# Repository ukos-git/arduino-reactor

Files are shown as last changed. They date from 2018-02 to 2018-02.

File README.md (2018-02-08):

# arduino-reactor
This Arduino program controls various parameters during the production of Single Walled Carbon Nanotubes (SWNT). It has a simplification for the Modbus Protocol for a EUROTHERM 2416 PID controller. The readout of pressure and flowmeters is done with analog input values.
The output and input of the arduino is simple ASCII plain text at the USB port.

Readout can be directed to a python based visual terminal manged by [python-swnt-reactor](https://github.com/ukos-git/python-swnt-reactor)

# setup
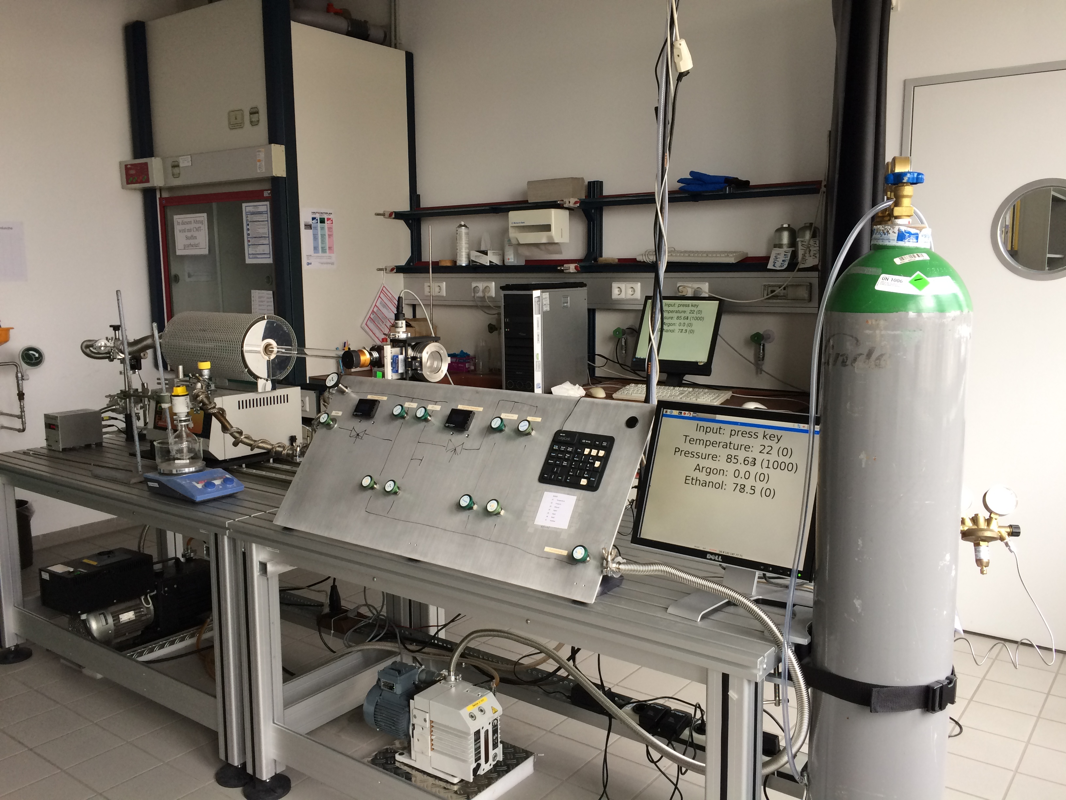
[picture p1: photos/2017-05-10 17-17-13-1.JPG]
photos/2017-05-10 17-17-13-1.JPG

The setup consists of an oven with a centered quarz tube. Inside the quarz pipe the sample is placed. The oven can be moved so that the sample is in the center of the oven during reaction. Reaction (carbon nanotube formation) takes place at 725-900°C with a pressure of around 15mbar.

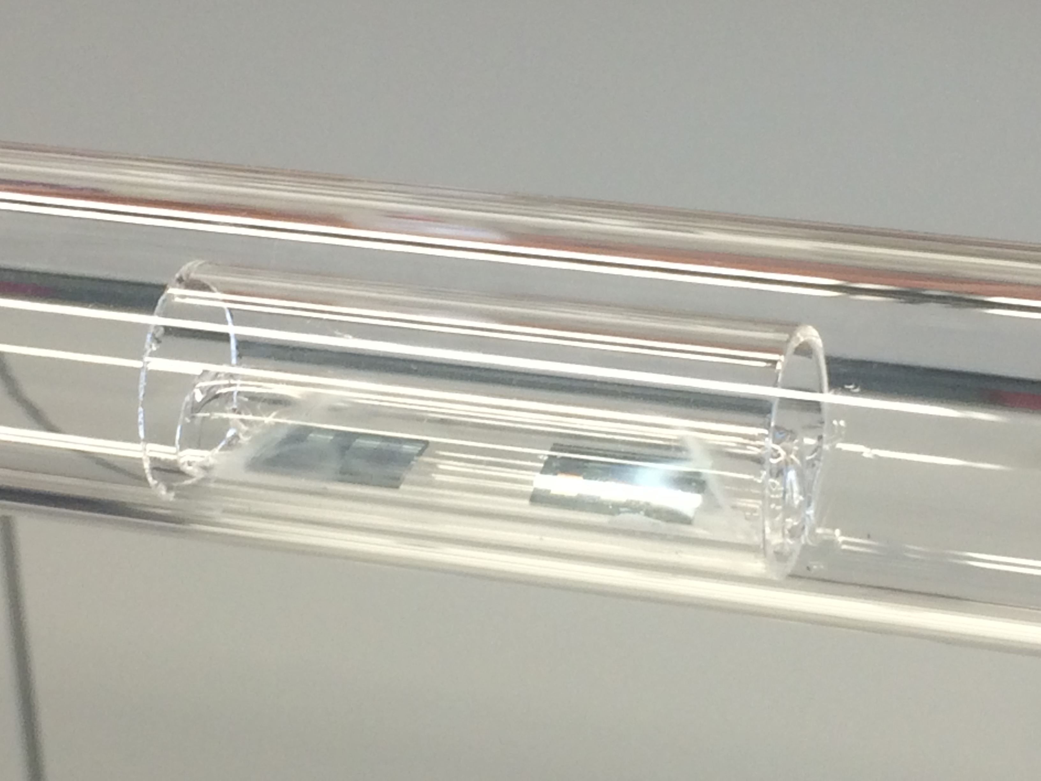
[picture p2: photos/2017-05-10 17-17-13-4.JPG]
sample in quartz tube


The process gas for the Carbon Source is Ethanol, supplied in liquid form and evaporated at 15mbar. Flow is controlled by a Bronkhorst EL-Flow FlowMeter. Digital control of the flowmeter is done in [another project](https://github.com/ukos-git/python-flowmeter).

Reduction of the Catalyst is done via Ar/H<sub>2</sub> gas flow during heat-up.

The Setup can be evacuated to <1mbar and flooded with Argon after reaction.

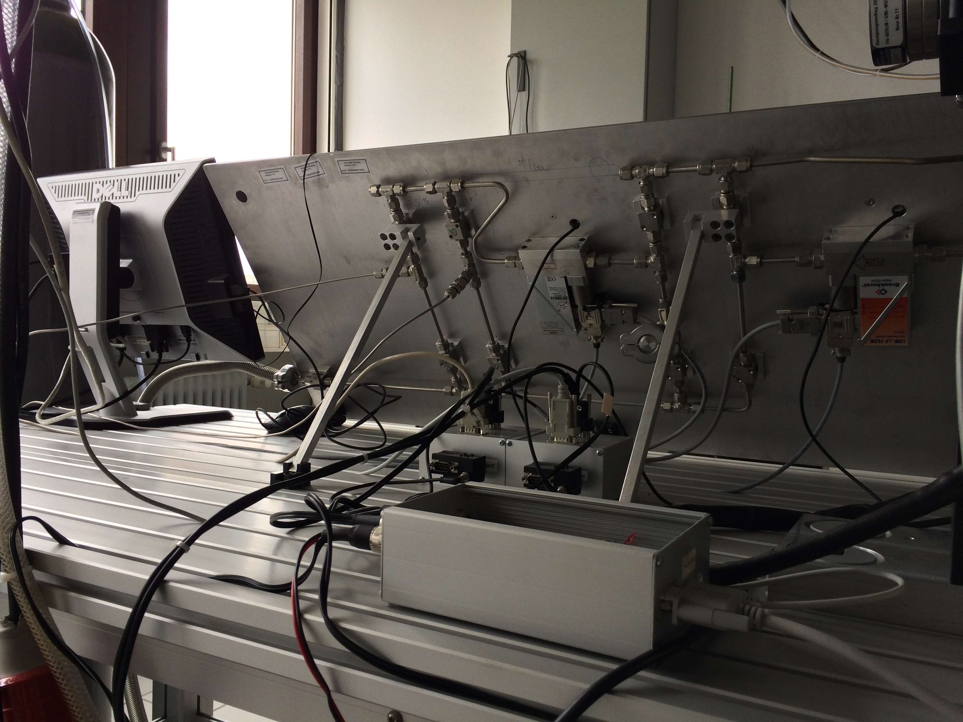
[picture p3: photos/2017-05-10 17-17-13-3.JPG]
process gas wiring


# arduino wiring.

bread board planning|  final setup
:-------------------------:|:-------------------------:
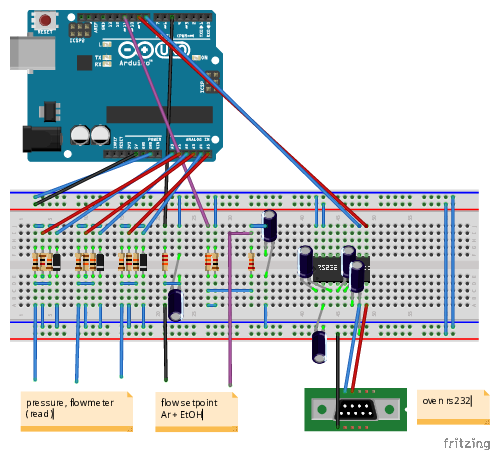
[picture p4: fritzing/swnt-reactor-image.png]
wiring fritzing
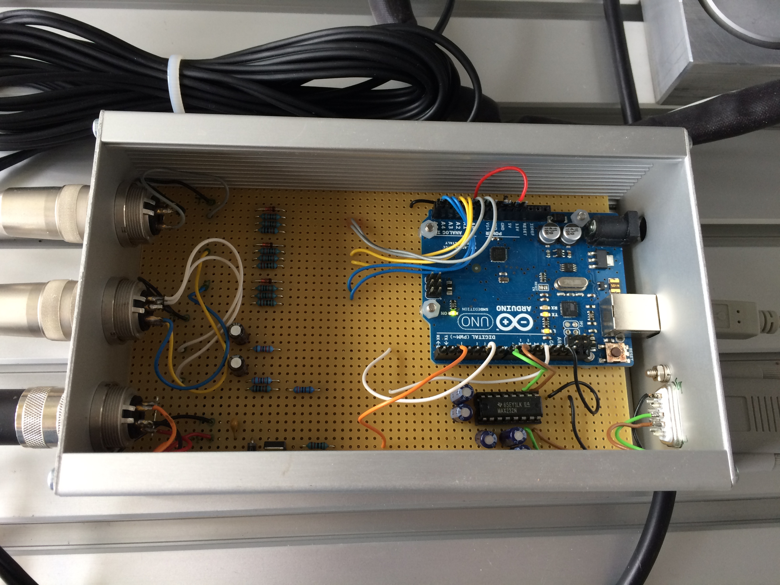
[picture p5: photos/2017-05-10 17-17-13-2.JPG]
wiring photo
  | 

technical wring is shown in the following schematic.

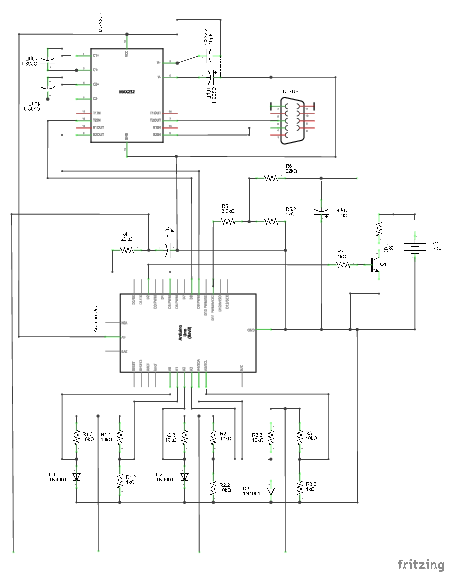
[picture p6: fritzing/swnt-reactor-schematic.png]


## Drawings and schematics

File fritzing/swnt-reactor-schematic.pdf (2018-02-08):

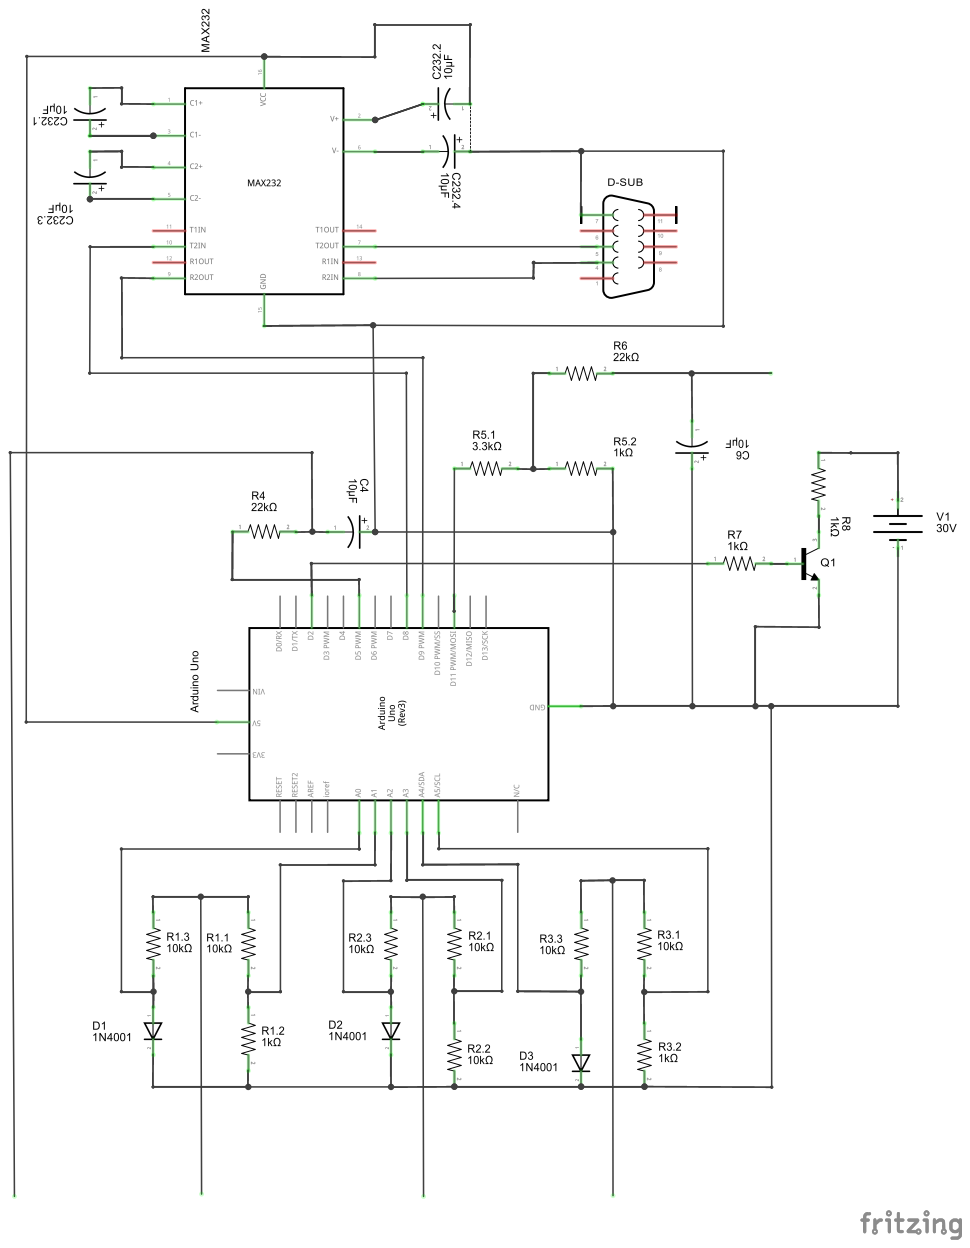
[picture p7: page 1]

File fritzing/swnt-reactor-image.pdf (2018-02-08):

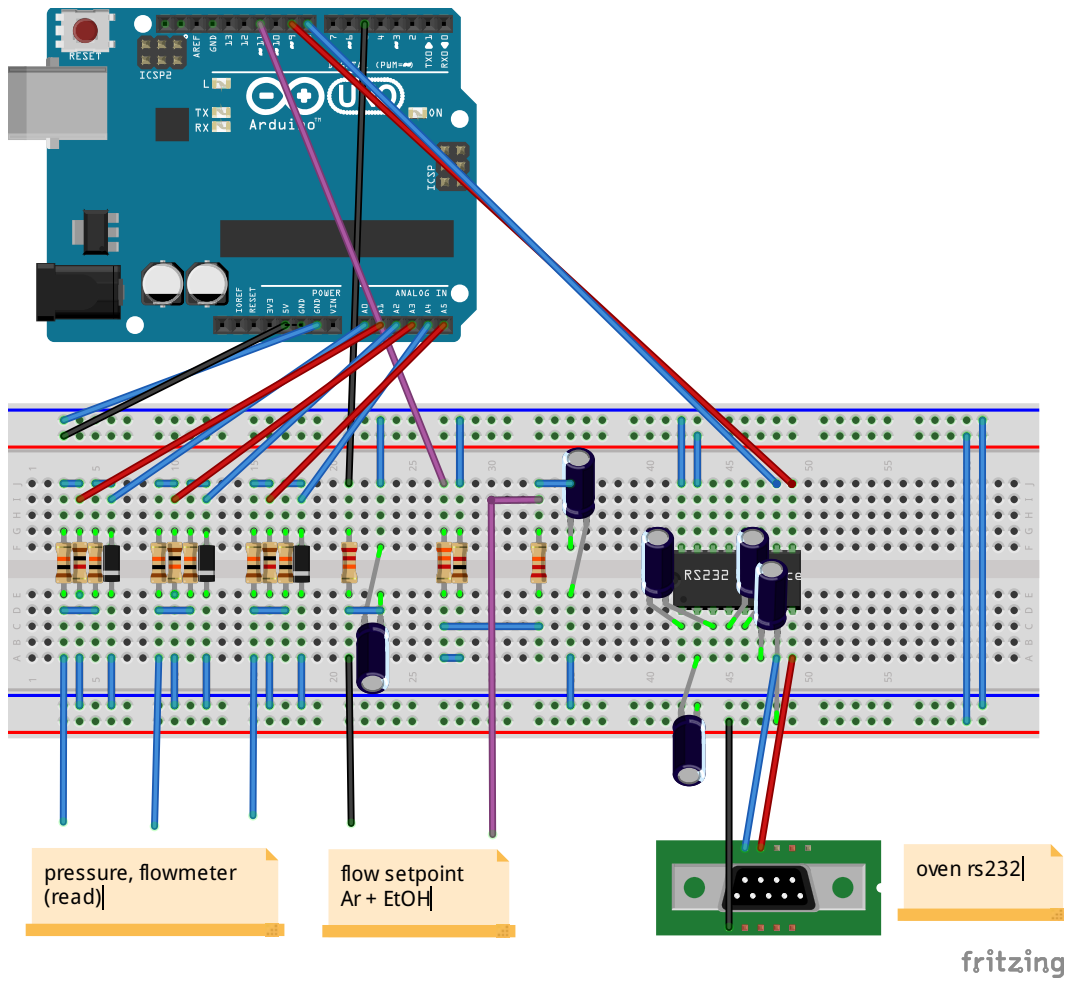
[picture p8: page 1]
flo; oin

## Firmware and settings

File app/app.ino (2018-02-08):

#include <SoftwareSerial.h>
#include <MKModbus.h>
#include <MKTemperature.h>

//SoftwareSerial Eurotherm2416(9, 8, true);   // Init Eurotherm PID Controller on Ports rx,tx,convert the ttl by software
SoftwareSerial Eurotherm2416(9, 8);           // Init Eurotherm PID Controller on Ports rx,tx,convert the ttl by hardware
MKModbus Modbus(Eurotherm2416);               // Init Modbus Protocol for Eurotherm PID Controller
MKTemperature Temperature(Modbus);            // Init Oven with attached Eurotherm Controller

#include <MKFlow.h>
MKFlow Argon;
MKFlow Ethanol;

#include <MKPressure.h>
MKPressure Pressure;

#include <MKUserInput.h>
MKUserInput Input;

#include <MKMath.h>
MKMath Math;

long runtime=0;

void setup()
{
  //INIT
  Serial.begin(9600);
  Eurotherm2416.begin(9600);
  Input.setInput(Serial);
  Pressure.init (A1, A0, 2,  1000, 11.078, 1.02);       // pin in1, pin in2, pin out, max, div1(in), div2(in), div3(out)
//  Ethanol.init  (A3, A2, 11, 6500, 11.0, 1.017, 5.520529461, 234.8957289, 0);    // Ethanol factory default 285mbar 50°C  
  Ethanol.init  (A3, A2, 11, 6817, 11.0, 1.017, 5.467162915, 250.1738099, 0);    // Ethanol 15mbar 32°C
//  Ethanol.init  (A3, A2, 11, 7272, 11.0, 1.017, 5.502342313, 262.5962413, 0);    // Methanol 15mbar 32°C
//  Ethanol.init  (A3, A2, 11, 6709, 11.0, 1.017, 5.464545339, 248.0806556, 0);    // 1Propanol 15mbar 32°C  
//  Ethanol.init  (A3, A2, 11, 7545, 11.0, 1.017, 5.490258893, 280.8848865,0);     // 1Butanol 15mbar 32°C     
  Argon.init    (A5, A4, 5,  2500, 11.0, 1.00, 1.28581846, 19.90550708, 0);

}

void loop()
{ 
  checkinput();
  //wait(1000);  
  //printTime();
  Serial.print((float)millis()/1000.0);
  Temperature.batch(Math,2); //Temperature change is very low and Modbus protocol is slow
  printTemperature(); 
  Pressure.batch(Math,64);
  printPressure();  
  Argon.batch(Math,64);
  printArgon();  
  Ethanol.batch(Math,64);
  printEthanol();
  Serial.println();
  Pressure.check();
  secure();
}

void secure()
{
  if (Pressure.getValue()>980.0)
  { 
      Argon.set(0);
      Ethanol.set(0);
      //Pressure.set(1000);
  }
    
}
void printTime()
{
  int  minute=0;
  byte second=0;
  float time =0.0;
  time   = (float)millis()/1000.0/60.0;
  minute = (int)(time);
  second = (byte)((time-(float)minute)*60);
  Serial.print(minute);
  Serial.print(":");  
  Serial.print(second);  
}

void wait(long millisecond)
{
  long now     = 0;
  long waittime= 0;
  now = millis();
  waittime = millisecond - (now - runtime);
  if (waittime<0) {waittime=0;}
  delay(waittime);
  runtime = now;
}

void printTemperature()
{
  Serial.print("\tTemp\t");
  Serial.print(Temperature.getTemperature());
  Serial.print("\t");
  Serial.print(Temperature.getTDeviation());
  Serial.print("\t");
  Serial.print(Temperature.getError());  
  Serial.print("\t");
  Serial.print(Temperature.getSetPoint());
  
  Serial.print("\tPower\t");  
  Serial.print(Temperature.getPower());
/*  Serial.print("\t");
  Serial.print(Temperature.getPDeviation());
  Serial.print("\t");
  Serial.print(Temperature.getError());
  Serial.print("\t");
  Serial.print(Temperature.getSetPointPower());  */
}

void printPressure()
{
  Serial.print("\tPress\t");  
  Serial.print(Pressure.getValue());
  Serial.print("\t");  
  Serial.print(Pressure.getDeviation());
  Serial.print("\t");
  Serial.print(Pressure.getError());
  Serial.print("\t");
  Serial.print(Pressure.getSetPoint());
}

void printEthanol()
{
  Serial.print("\tEtOH\t");  
  Serial.print(Ethanol.getValue());
  Serial.print("\t");  
  Serial.print(Ethanol.getDeviation());
  Serial.print("\t");
  Serial.print(Ethanol.getError());
  Serial.print("\t");
  Serial.print(Ethanol.getSetPoint());
}

void printArgon()
{
  Serial.print("\tArgon\t");  
  Serial.print(Argon.getValue());
  Serial.print("\t");  
  Serial.print(Argon.getDeviation());
  Serial.print("\t");
  Serial.print(Argon.getError());
  Serial.print("\t");
  Serial.print(Argon.getSetPoint());
}

void checkinput()
{
  Input.waitfor('t','/');  
    if (Input.ready()) { Temperature.set(Input.receive()); }
  Input.waitfor('p','*');  
    if (Input.ready()) { Pressure.set(Input.receive()); }
  Input.waitfor('a','-');  
    if (Input.ready()) { Argon.set(Input.receive()); }
  Input.waitfor('e','+');  
    if (Input.ready()) { Ethanol.set(Input.receive()); }  
  Input.waitfor('d',',');
    if (Input.ready()) 
    { 
      word value = Input.receive();
      switch (value) {
      case 1:
        Temperature.debug(Serial);
      break;
      case 2:
        Pressure.debug(Serial);
      break;
      case 3:
        Ethanol.debug(Serial);
      break;
      case 4:
        Argon.debug(Serial);
      break;
      case 5:
        Input.debug(Serial);
      break;      
      case 6:
        Math.debug(Serial);
      break;
      case 7:
        Modbus.debug(Serial);
      break;      
      }
    } 
  Input.clear();  
}

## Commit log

2018-02-08 initial commit
    Program simplifies communication with a reactor for swnt production:
    * oven (RS232)
    * flow meter and pressure sensors (analog)
    [swnt-reactor.fzz]
2018-02-08 fritzing-schematic
    add link to pdf since it has a better resolution than the converted pdf.
